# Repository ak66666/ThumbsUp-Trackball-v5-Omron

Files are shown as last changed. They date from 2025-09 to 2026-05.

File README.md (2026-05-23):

# ThumbsUp! Trackball v5 Omron
A version of v3 with Omron D2FC-7 switches used instead of Kailh Chocs.
PCB is used as button caps.

Finger-controlled configuration.
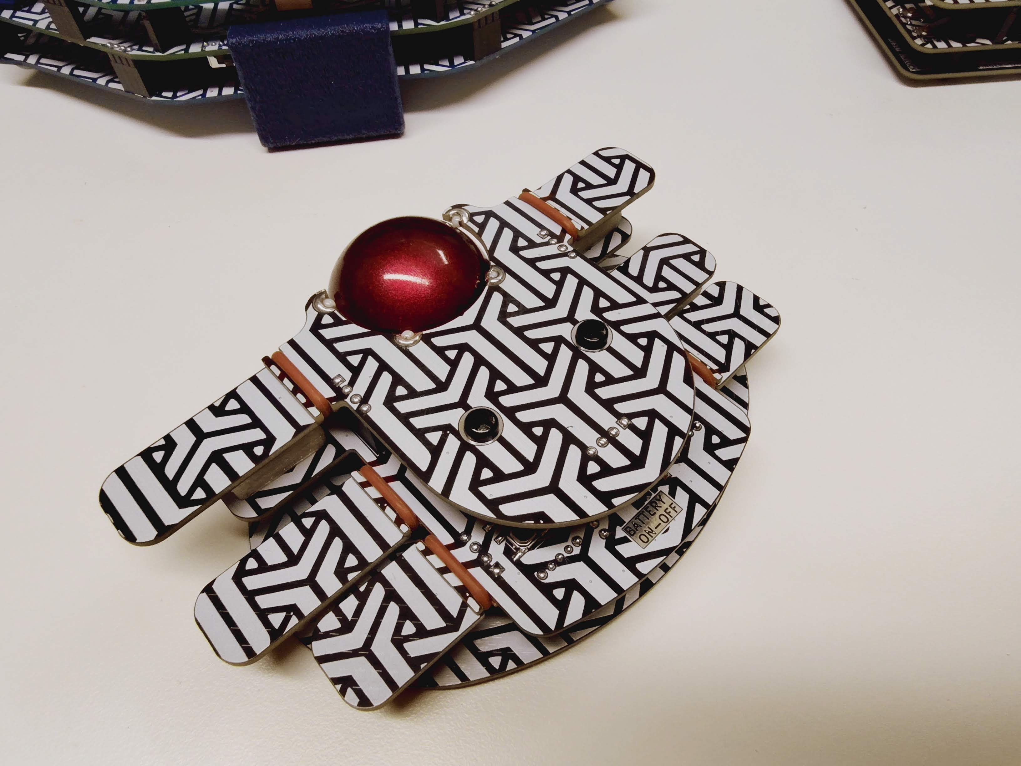
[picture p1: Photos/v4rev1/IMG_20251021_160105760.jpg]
Photos


For the thumb-operated mode a back(top) palm support is included.
For the right-hand operation mirror the model in slicer.

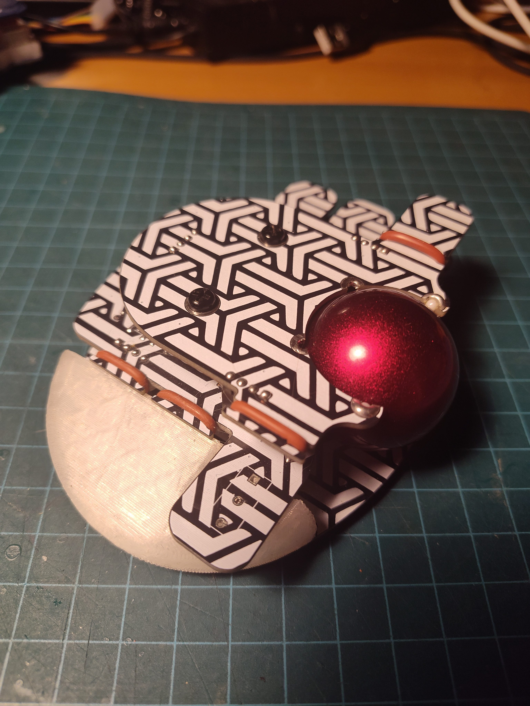
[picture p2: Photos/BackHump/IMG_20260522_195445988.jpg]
Photos

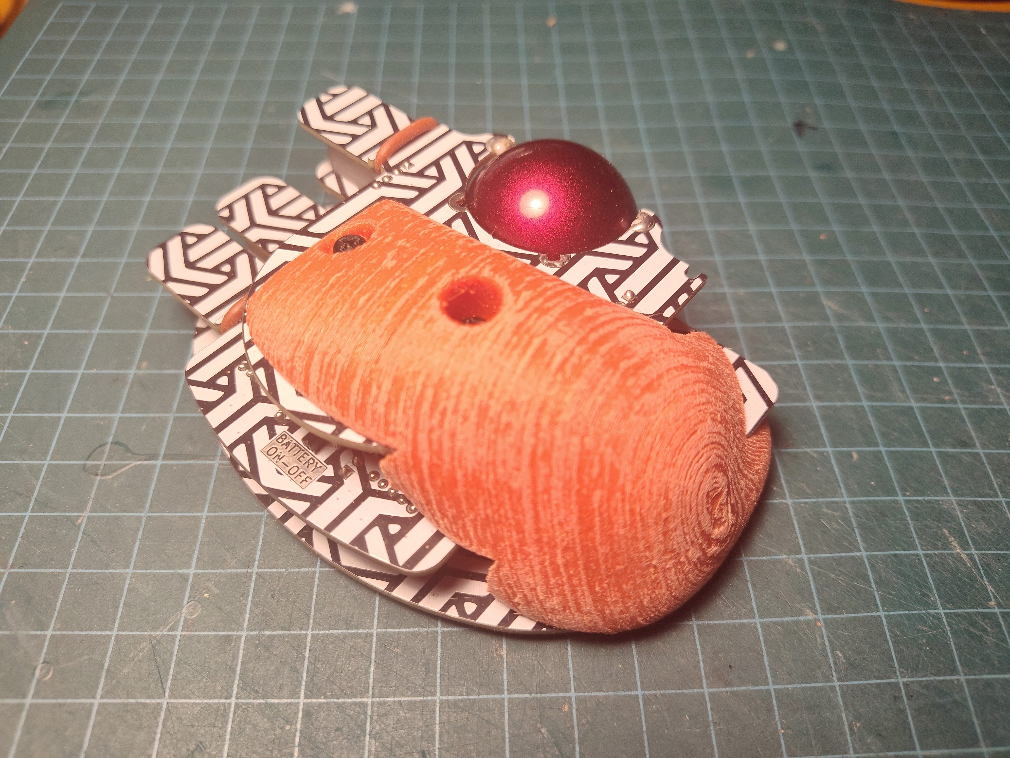
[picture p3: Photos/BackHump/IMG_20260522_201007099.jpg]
Photos

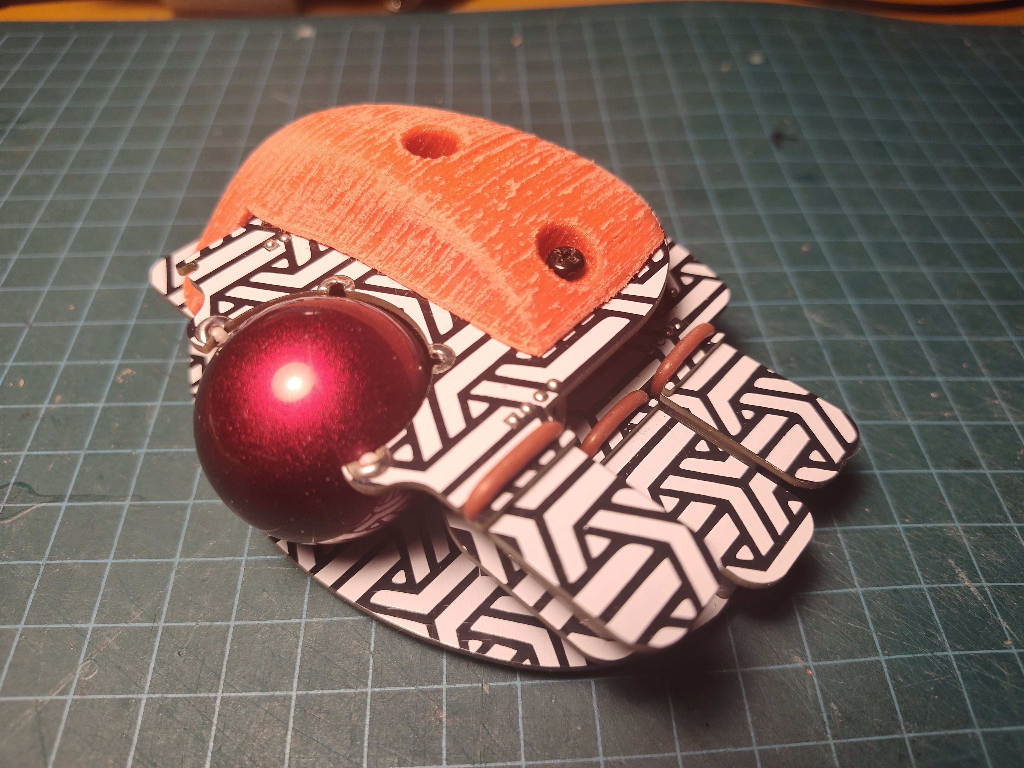
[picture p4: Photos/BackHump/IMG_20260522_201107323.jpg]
Photos

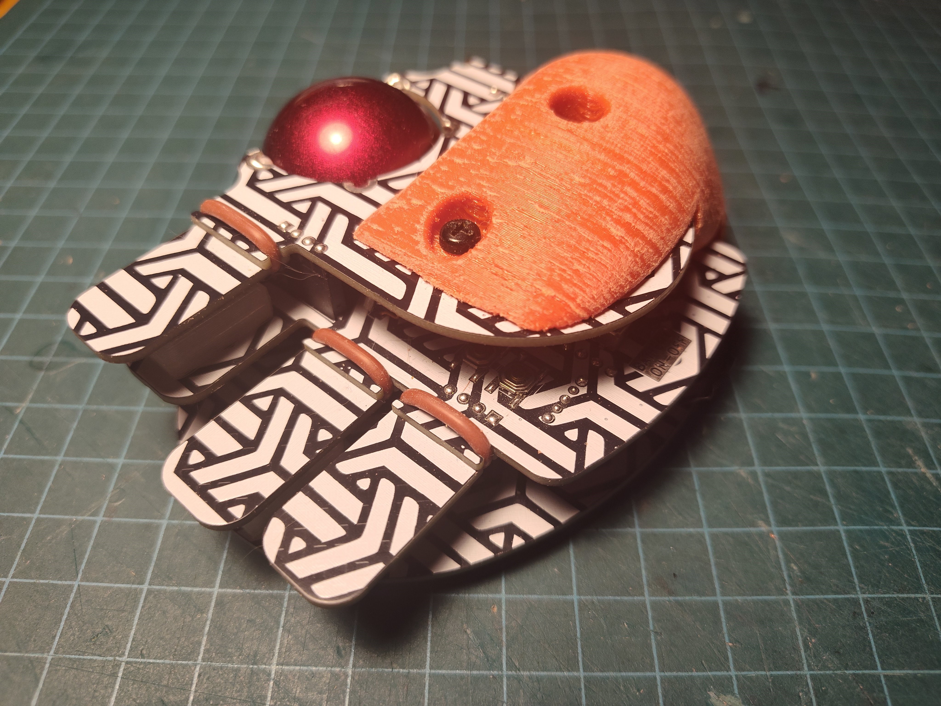
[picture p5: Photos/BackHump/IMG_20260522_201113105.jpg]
Photos


A PCB-based thumb-operated trackball, inspired by Elecom EX-G left hand trackball, Ploopy Nano trackball, and my own ThumbsUp! keyboards.

To be suitable for both left- and right-hand usage (in "portrairt" orientation), and also be finger-operated (in "landscape").
A three-position switch/soldering pad tells the device which mode to use - that will define the rotating direction.

It is a continuation of Trackball v3 - with the Kailh Choc switches replaced with Omron mouse buttons.
 
For MCU nice!nano v2 (and clones) with ZMK-based firmware is used (wired or wireless through Bluetooth or a dongle.)

34 mm ball, same as in Elecom EX-G.
For bearings - uxcell 2.5mm Ceramic Bearing Balls, ZrO2 Zirconium Oxide Ball, again, the same as used to improve my Elecom trackballs.
Bearings to be implanted into PCBs, no 3D-printed ball shroud/holder.

Other pictures in Photos folder.

# Firmware - same as v3

Original version with BT and wired connection:
https://github.com/ak66666/zmk-config-trackball.v3        

Dongle version:
https://github.com/ak66666/zmk-config-trackball.v3.dongle

Dongle version for a combo with ThumbsUp! v9 keyboard:
https://github.com/ak66666/zmk-config-trackball-v3-and-keyboard-v9.dongle

# For sale on Etsy
 
https://www.etsy.com/ca/listing/4390955764

# Assembly Instructions

Similar to v3:
https://thumbsupkeyboards.blogspot.com/2025/09/thumbsup-trackball-v3-assembly-steps.html

The difference is in the switches only.
3D printed switch bases are needed.
Below the switches there are three-point soldering connectors - you need to close two of them on the side where the switch button is.

# Gerber Generation

There is a little trick that needs to be applied to produce silkscreens with overlapping labels.
Normally all the elements on the silkscreen are added up, so the text would be interrupted/covered by the drawing elements.

To work around that limitation - use the generation option "Subtract Soldermask from Silkscreen".
IMPORTANT: Save and preserve the project files, you will be temporarily removing parts of the board design.

Labels which are covered by the silkscreen pattern, they should be moved to the front/back soldering mask layer.
Text needs to be inverted - check "Knockout" box in the label properties.
On the matching front/back silkscreen layer add a rectangle around the label. 
For the design time leave it unfilled - will fill it during Gerber file generation as described below.

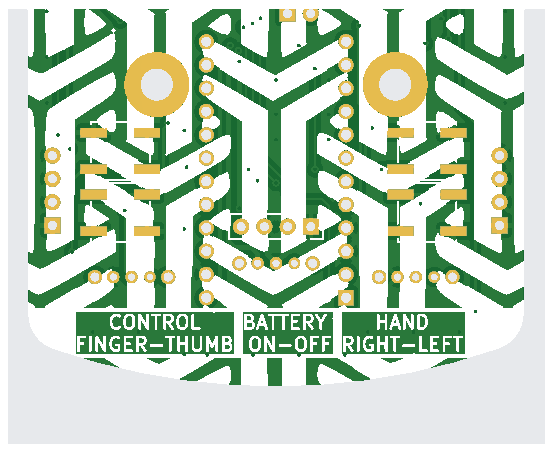
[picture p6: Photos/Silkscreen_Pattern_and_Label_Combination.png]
Photos


To generate fabrication files:
- In PCB Editor, for each of the PCB do the following (_do not_ save the file while doing that):
	- Select and delete all other PCBs, leave only one to be generated.
	- For each label on the solder mask layer - locate silkscreen rectangles around that label, modify its property - check "Filled Shape" box.
	  (Those boxes are not filled while designing the board, otherwise they cover all other elements.)
	- Generate the Gerbers (plotting, drilling files) with this:
		- Uncheck  "Subtract Soldermask from Silkscreen" option.
		- Exlude the silkscreens at this point.
	- Generate silkscreen layers with  "Subtract Soldermask from Silkscreen" option checked.
	- Close PCB Editor without saving the file.
	- Re-open PCB Editor and repeat these steps for other boards.
- Verify the genearted files.

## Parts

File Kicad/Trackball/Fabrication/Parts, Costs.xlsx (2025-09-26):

# | Part | Quantity | Price, CAD | Cost, CAD | Source
1 | PMW3610 sensor and lens | 1 | 5.99 | 5.99 | https://www.aliexpress.com/item/1005007118767775.html
2 | Nice!nano v2 (or clone) | 1 | 6.70 | 6.70 | https://www.aliexpress.com/item/1005006074191337.html
3 | 34mm ball | 1 | 19.08 | 19.08 | https://www.aliexpress.com/item/1005007857787050.html
4 | 3.7V 110mAh 301230 Lithium Polymer Li-Po Battery | 1 | 2.24 | 2.24 | https://www.aliexpress.com/item/1005003662352305.html
5 | Kailh Choc hot-swap sockets | 6 | 0.19 | 1.14 | https://www.aliexpress.com/item/1005003873653184.html
6 | Kailh Choc White Clicky swithces | 6 | 1.00 | 6.00
7 | Kailh Choc Key Cap | 6 | 1.00 | 6.00
8 | 12 Pin Headers Low profile, for Nice!nano. | 2 | 0.09 | 0.19 | https://www.aliexpress.com/item/1005007217493310.html
9 | 12 Pin Sockets, Low profile, for Nice!nano. | 2 | 0.42 | 0.85 | https://www.aliexpress.com/item/1005006248653180.html
10 | 4pin Sockets and pin headers for them for the board stands. | 7 | 0.02 | 0.16 | https://www.aliexpress.com/item/1005005258694395.html
11 | 4pin Sockets and pin headers for them for the board stands. | 7 | 0.11 | 0.77 | https://www.aliexpress.com/item/1005003610333849.html
12 | 2.5mm ZrO2 Ceramic Balls | 7 | 0.51 | 3.58 | https://www.aliexpress.com/item/1005008831542121.html
13 | Slide Switches (Power, Orientation, Handiness) | 3 | 0.49 | 1.48 | https://www.mouser.ca/ProductDetail/655-1825232-1
14 | 5x5mm Tactile Switches | 4 | 0.51 | 2.05 | https://www.mouser.ca/ProductDetail/611-PTS525SKG15JSMTR
15 | 6x 8x3mm Bumpons | 6 | 0.04 | 0.26 | https://www.aliexpress.com/item/1005005287385986.html
16 | Stand-offs w/nuts | 4 | 0.10 | 0.39 | https://www.amazon.ca/dp/B0BR5MT7R1
17 | 0.5 washers | 4 | 0.09 | 0.38 | https://www.amazon.ca/dp/B0F29B674L
18 | M3 screws | 4 | 0.10 | 0.42 | https://www.amazon.ca/dp/B07C72FBZ6
19 | PCB set | 1 | 60.00 | 60.00 | Price as sold at Etsy, less if ordered 20 sets from JLCPCB by yourself
 | Total without PCBs |  | 38.70
 | Total |  | 98.70

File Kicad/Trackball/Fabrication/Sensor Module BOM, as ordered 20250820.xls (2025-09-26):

Comment | Designator | Footprint | JLCPCB Part #
1m | C2 | C_0402_1005Metric | C14445
3.3uF/16V | C4 | C_0805_2012Metric | C15850
10k | R3 | R_0603_1608Metric | C25804
0.1u | C3,C1,C5,C6,C8 | C_0402_1005Metric | C1525
TCR2EF19 | U3 | SOT-23-5 | C27416
0.01u | C7,C9 | C_0402_1005Metric | C15195

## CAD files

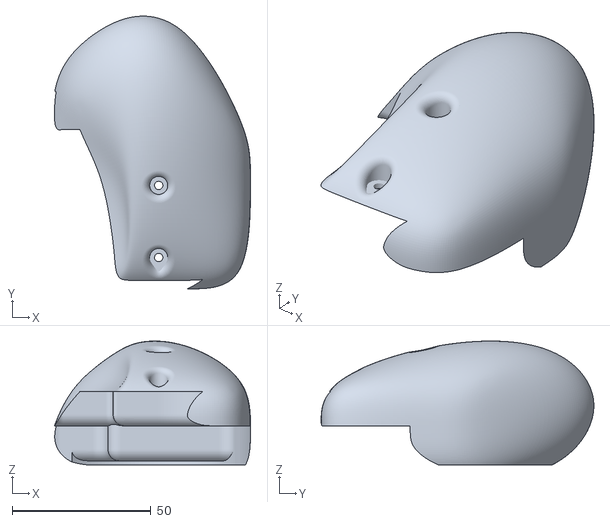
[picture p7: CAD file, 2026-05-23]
3D Parts/Hump2 Left.stl
70.6 x 98.2 x 44.6

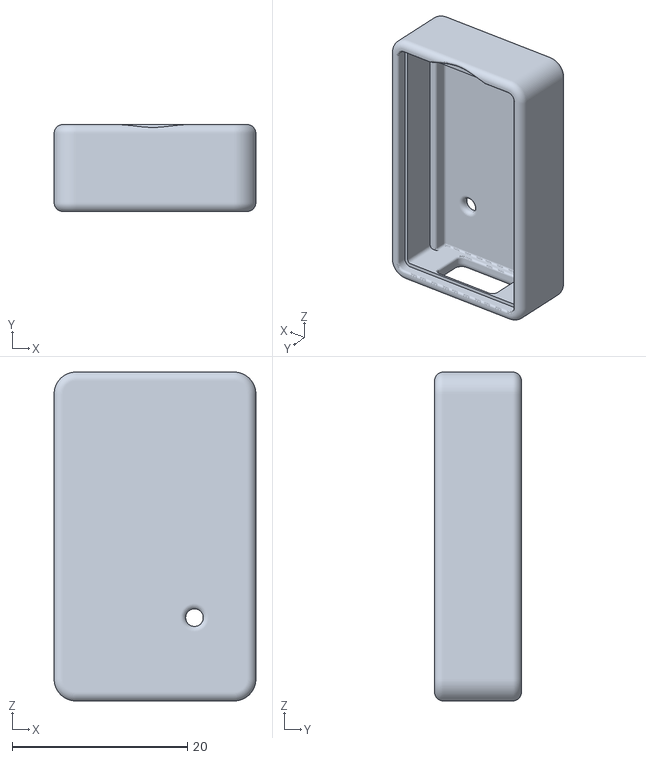
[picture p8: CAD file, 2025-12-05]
Dongle Case/Case.stl
23.0 x 9.90 x 37.5

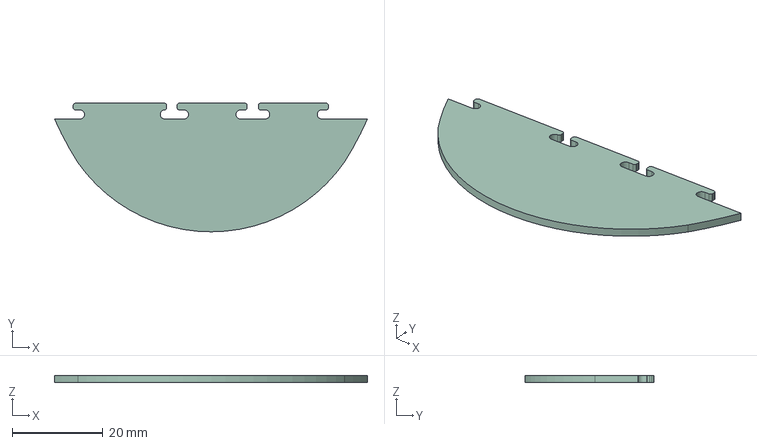
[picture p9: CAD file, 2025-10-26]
Kicad/Trackball/Palm Support/Palm Support.step
69.1 x 28.4 x 1.51 mm

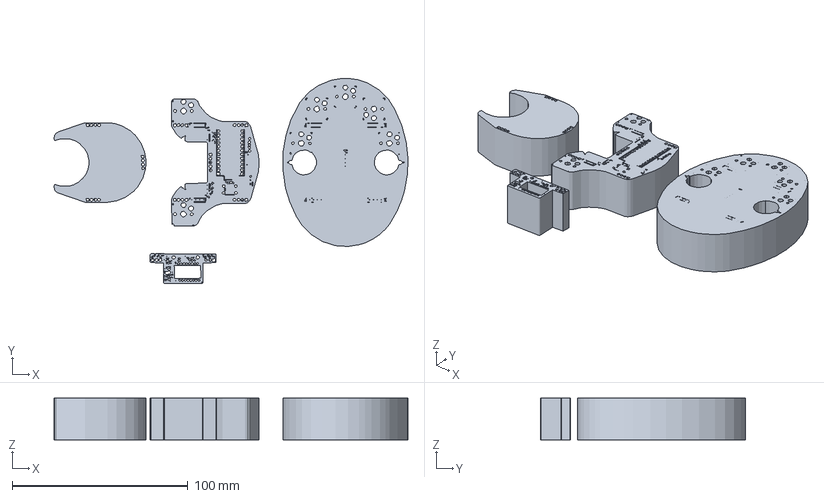
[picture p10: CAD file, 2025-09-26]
Kicad/Trackball/Pictures/PCBs.3mf
201.2 x 116.6 x 23.8 mm

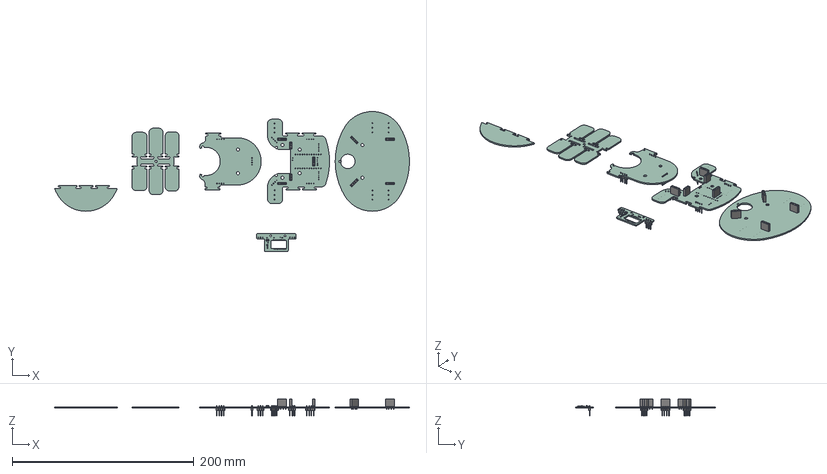
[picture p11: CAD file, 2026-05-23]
3D Parts/All Plates.step
391.0 x 154.1 x 18.7 mm
PinSocket_1x04_P2.54mm_Vertical x 7
C_0402_1005Metric x 8
PinSocket_1x03_P2.54mm_Vertical x 2
SOT-23-5
R_0603_1608Metric
C_0805_2012Metric
PinHeader_1x04_P2.54mm_Vertical x 7
PinHeader_1x03_P2.54mm_Vertical x 2
PinHeader_1x02_P2.54mm_Vertical
Trackball_PCB_1
Trackball_PCB_2
Trackball_PCB_3
Trackball_PCB_4
Trackball_PCB_5
Trackball_PCB_6

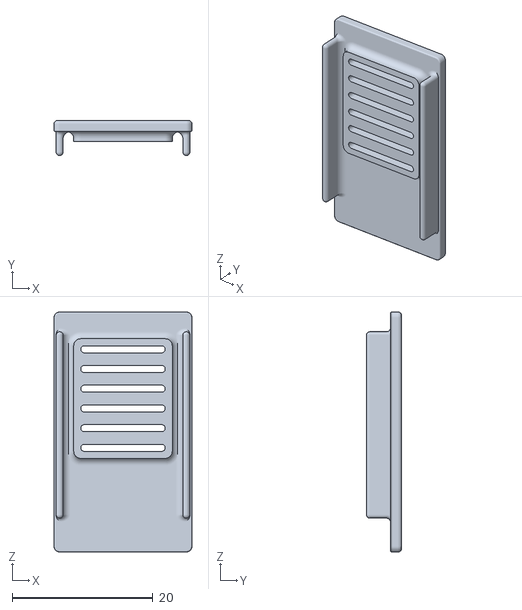
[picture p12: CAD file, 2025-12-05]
Dongle Case/Cover.stl
19.6 x 5.00 x 34.1

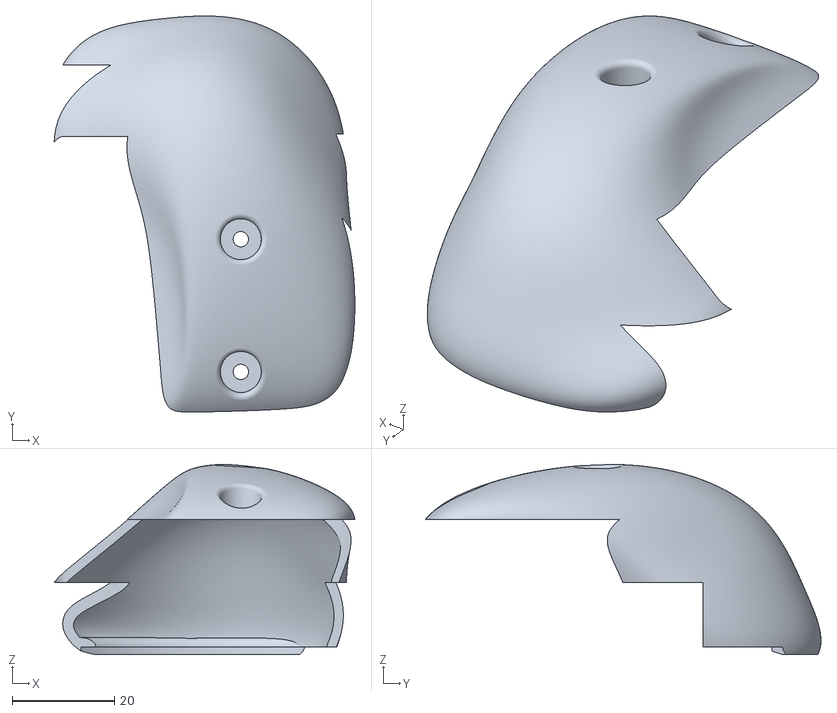
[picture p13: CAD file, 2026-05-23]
3D Parts/Hump Left.stl
58.8 x 77.5 x 37.2

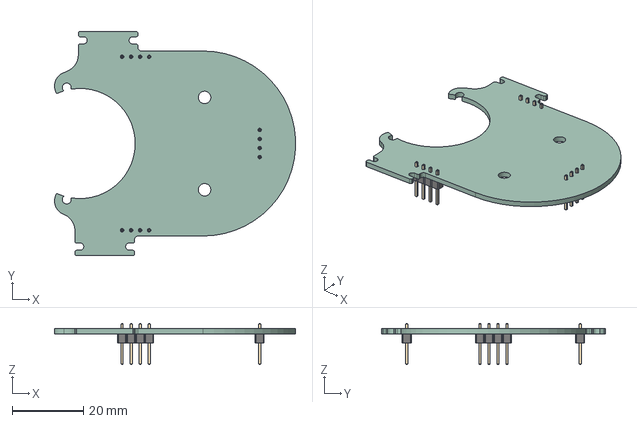
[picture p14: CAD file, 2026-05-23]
3D Parts/Top Plate.step
67.8 x 63.0 x 11.5 mm
PinHeader_1x04_P2.54mm_Vertical x 3
Trackball_PCB

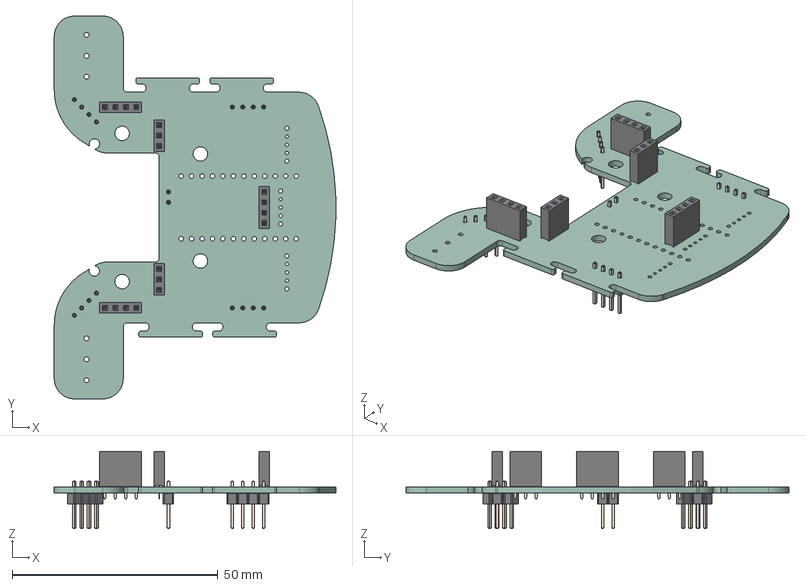
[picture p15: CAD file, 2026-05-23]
3D Parts/Middle Plate.step
68.4 x 93.0 x 18.7 mm
PinSocket_1x04_P2.54mm_Vertical x 3
PinSocket_1x03_P2.54mm_Vertical x 2
PinHeader_1x04_P2.54mm_Vertical x 4
PinHeader_1x02_P2.54mm_Vertical
Trackball_PCB

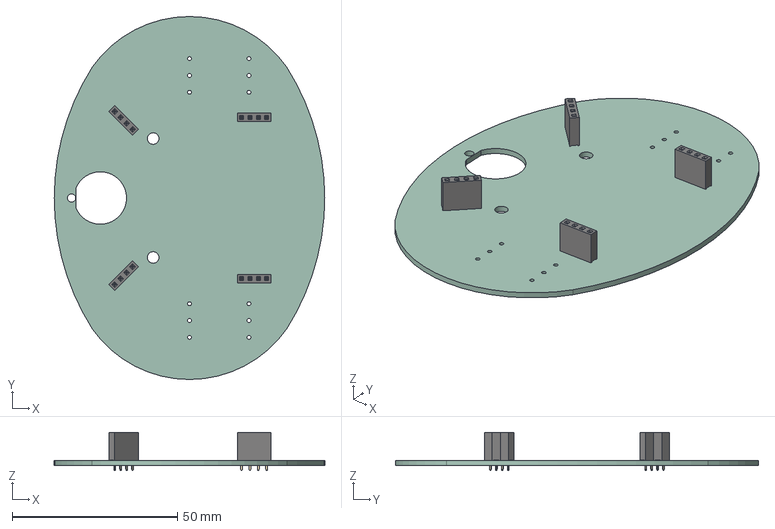
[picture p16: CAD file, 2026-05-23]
3D Parts/Bottom Plate.step
81.9 x 109.8 x 11.6 mm
PinSocket_1x04_P2.54mm_Vertical x 4
Trackball_PCB

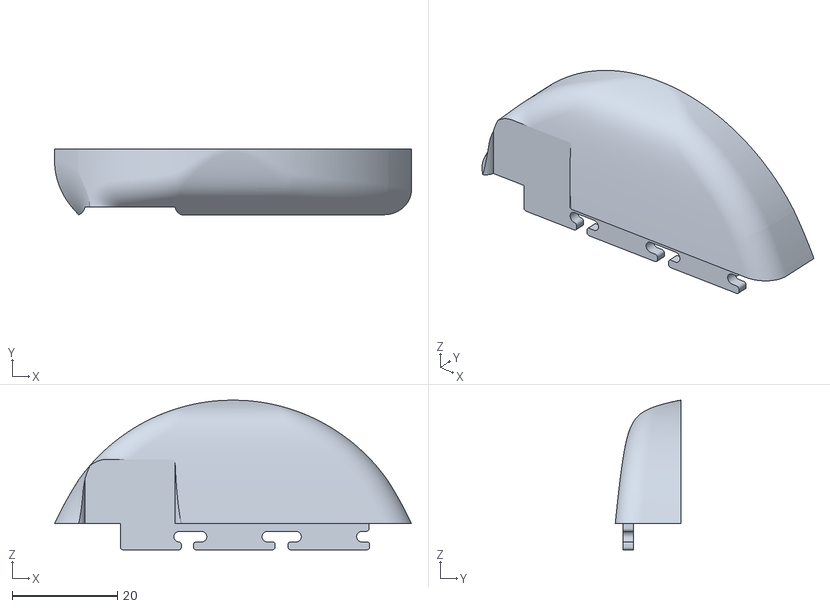
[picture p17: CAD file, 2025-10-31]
3D Parts/Palm Support.stl
67.8 x 12.4 x 28.4

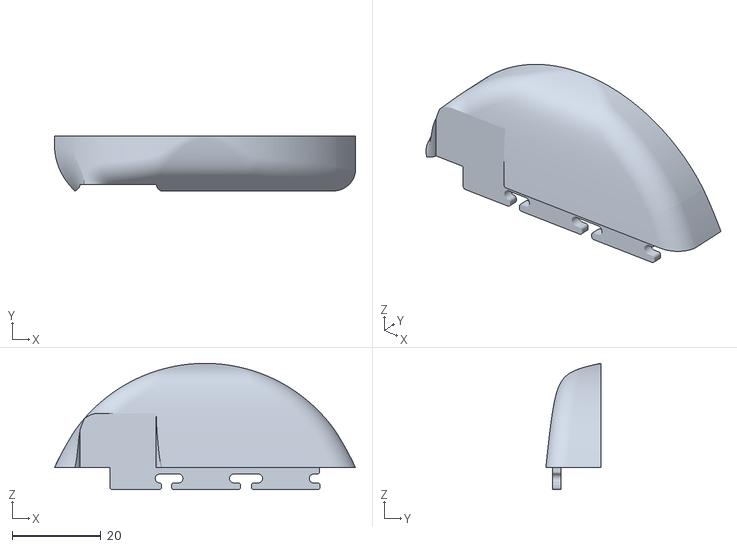
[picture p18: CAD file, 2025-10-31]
3D Parts/Palm Support Shell.stl
67.8 x 12.4 x 28.4

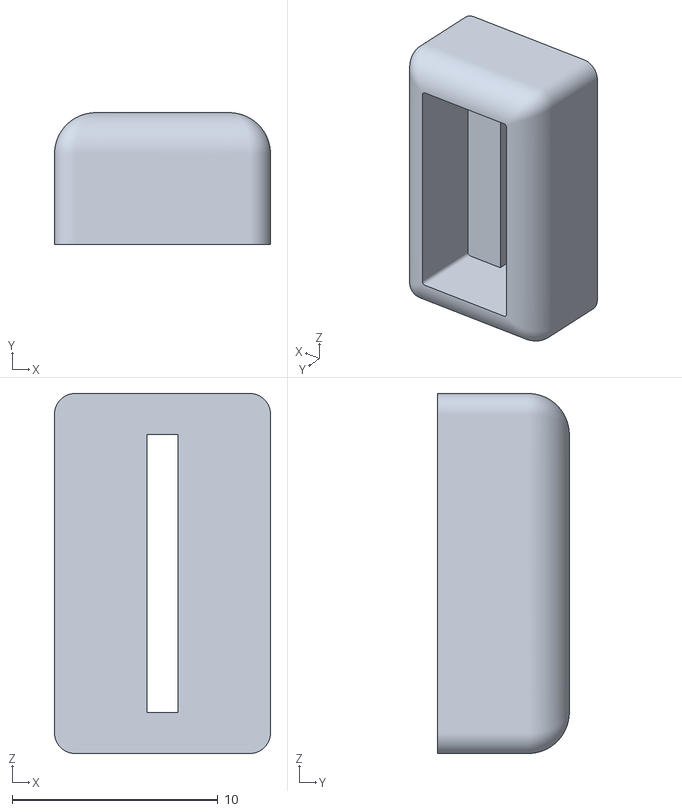
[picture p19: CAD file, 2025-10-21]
3D Parts/Switch Base 1.9.stl
10.5 x 6.40 x 17.5

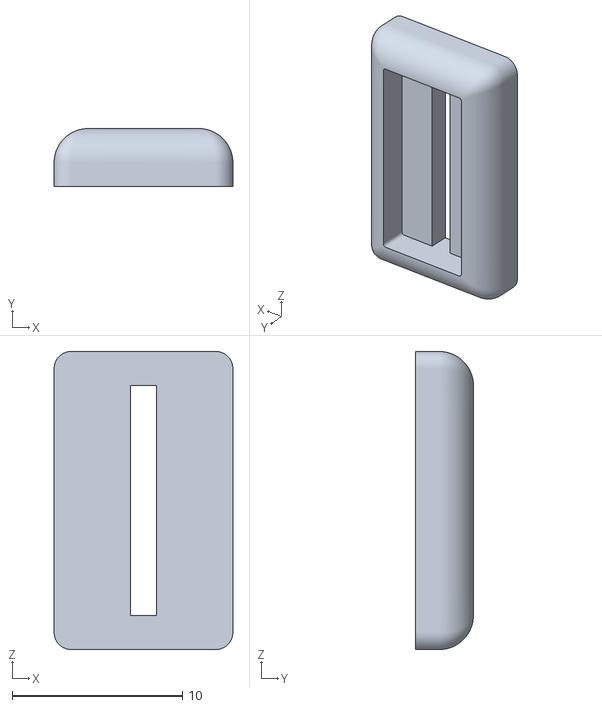
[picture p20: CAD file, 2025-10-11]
3D Parts/Switch Base Short.stl
10.5 x 3.40 x 17.5

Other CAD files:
3D Parts/Flap Holder.stl
3D Parts/Switch Base.stl
Kicad/Trackball/1825232-1/3D/1825232-1.stp
Kicad/Trackball/1825232-1/Allegro/18252321.psm
Kicad/Trackball/1825232-1/DEHDL/1825232_1/chips/chips.prt
Kicad/Trackball/Palm Support/Palm Support.stl

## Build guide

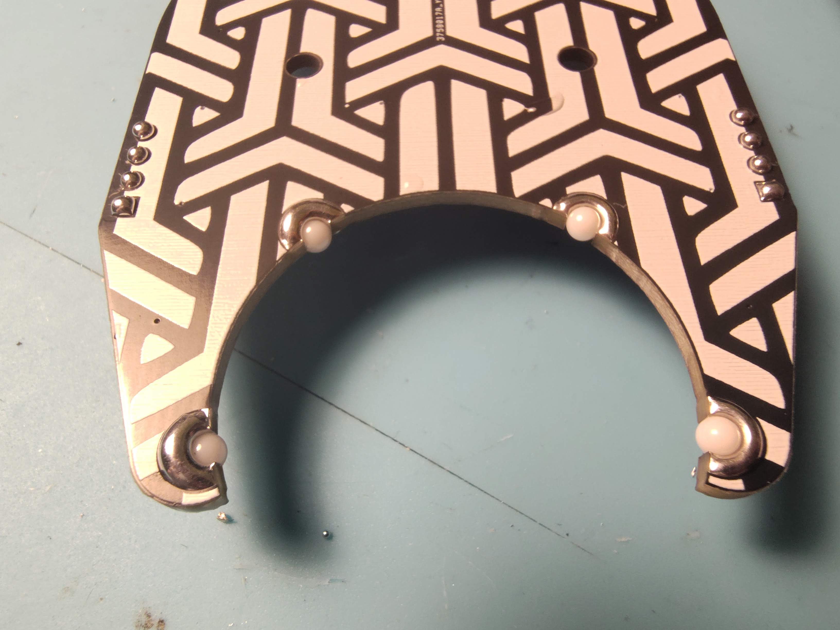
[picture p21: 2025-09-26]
Photos/Assembly Process/IMG_20250912_122234433.jpg

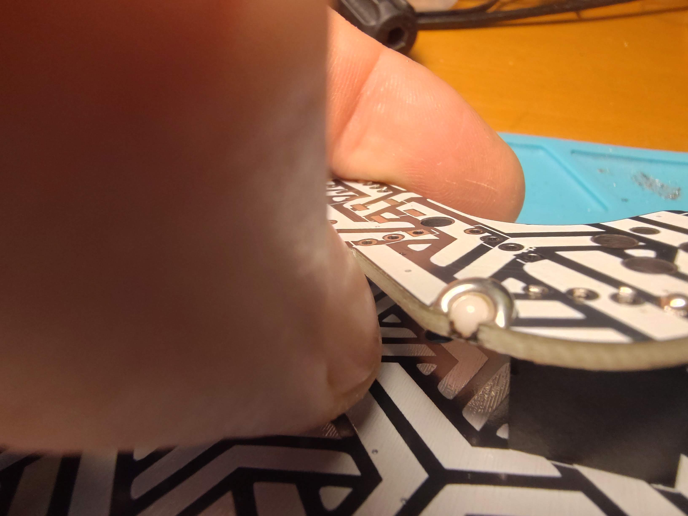
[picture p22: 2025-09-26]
Photos/Assembly Process/IMG_20250912_110531941_HDR.jpg

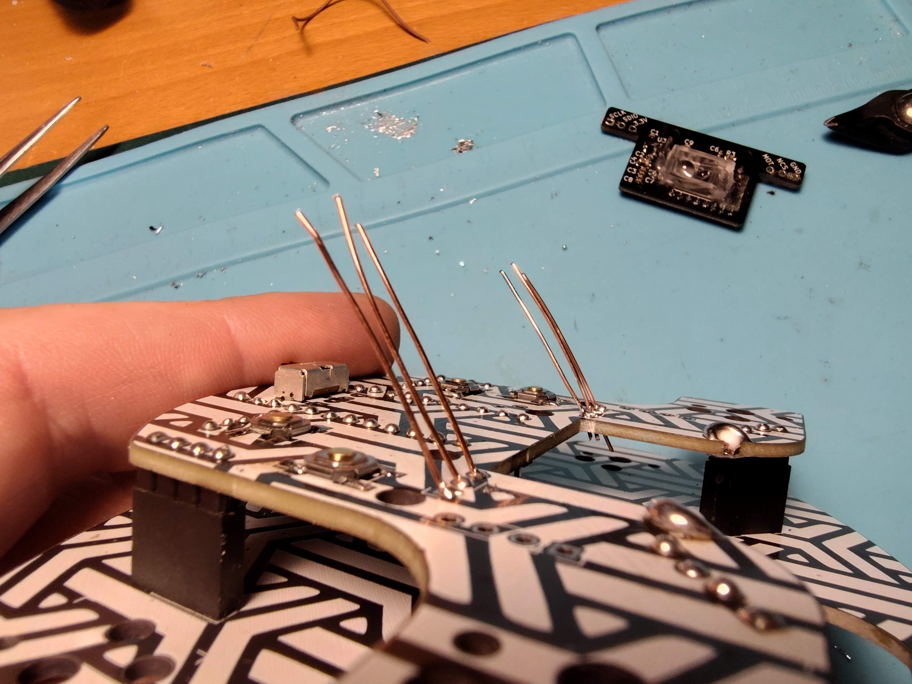
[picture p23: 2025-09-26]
Photos/Assembly Process/IMG_20250912_113103635_HDR.jpg

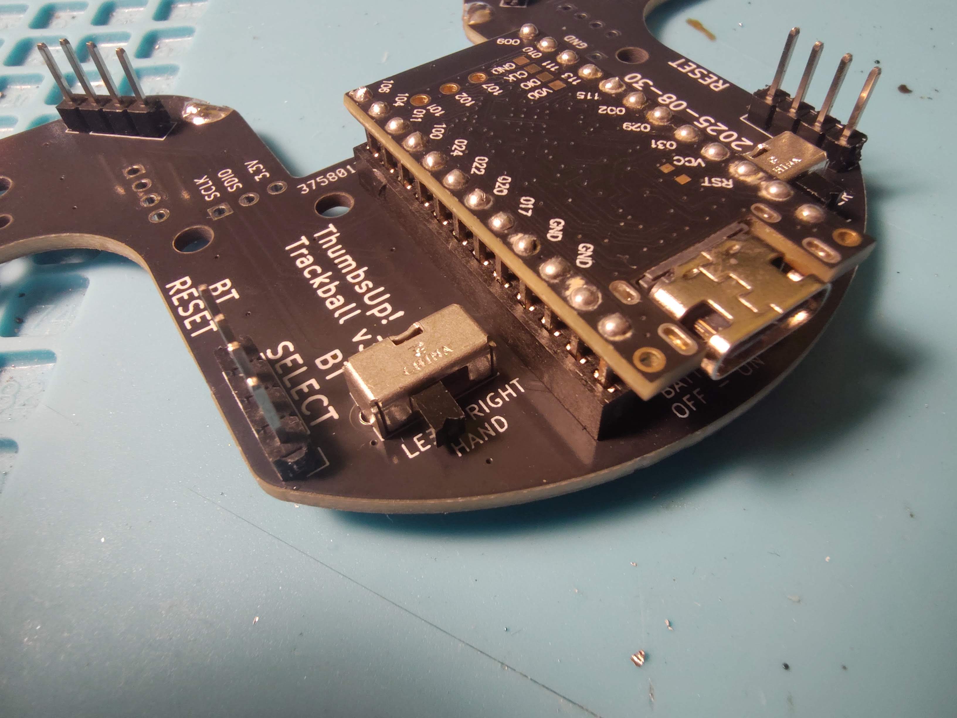
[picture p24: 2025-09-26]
Photos/Assembly Process/IMG_20250912_111534861.jpg

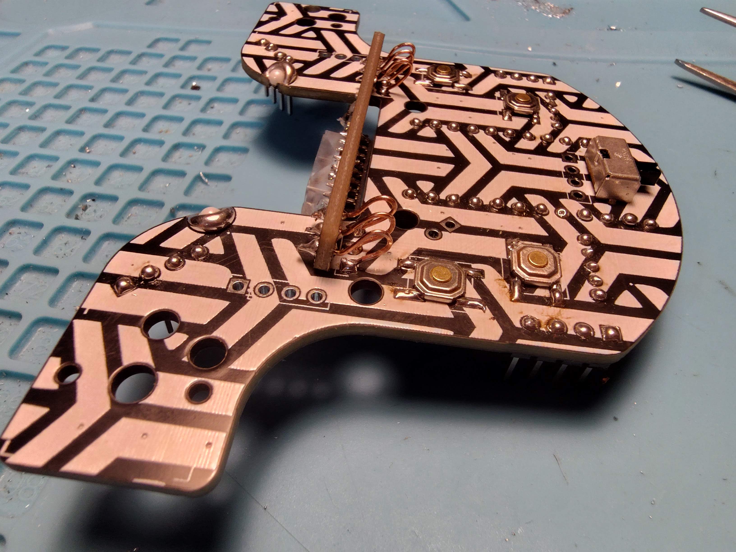
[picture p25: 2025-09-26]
Photos/Assembly Process/IMG_20250912_114000764_HDR.jpg

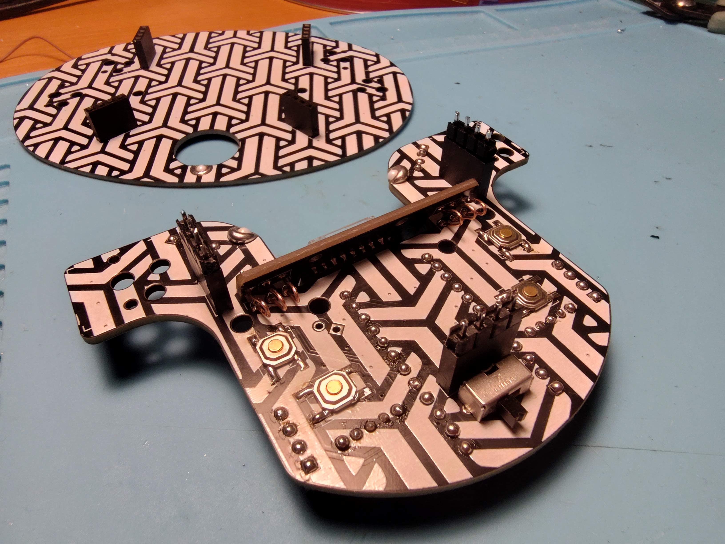
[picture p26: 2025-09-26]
Photos/Assembly Process/IMG_20250912_120129462_HDR.jpg

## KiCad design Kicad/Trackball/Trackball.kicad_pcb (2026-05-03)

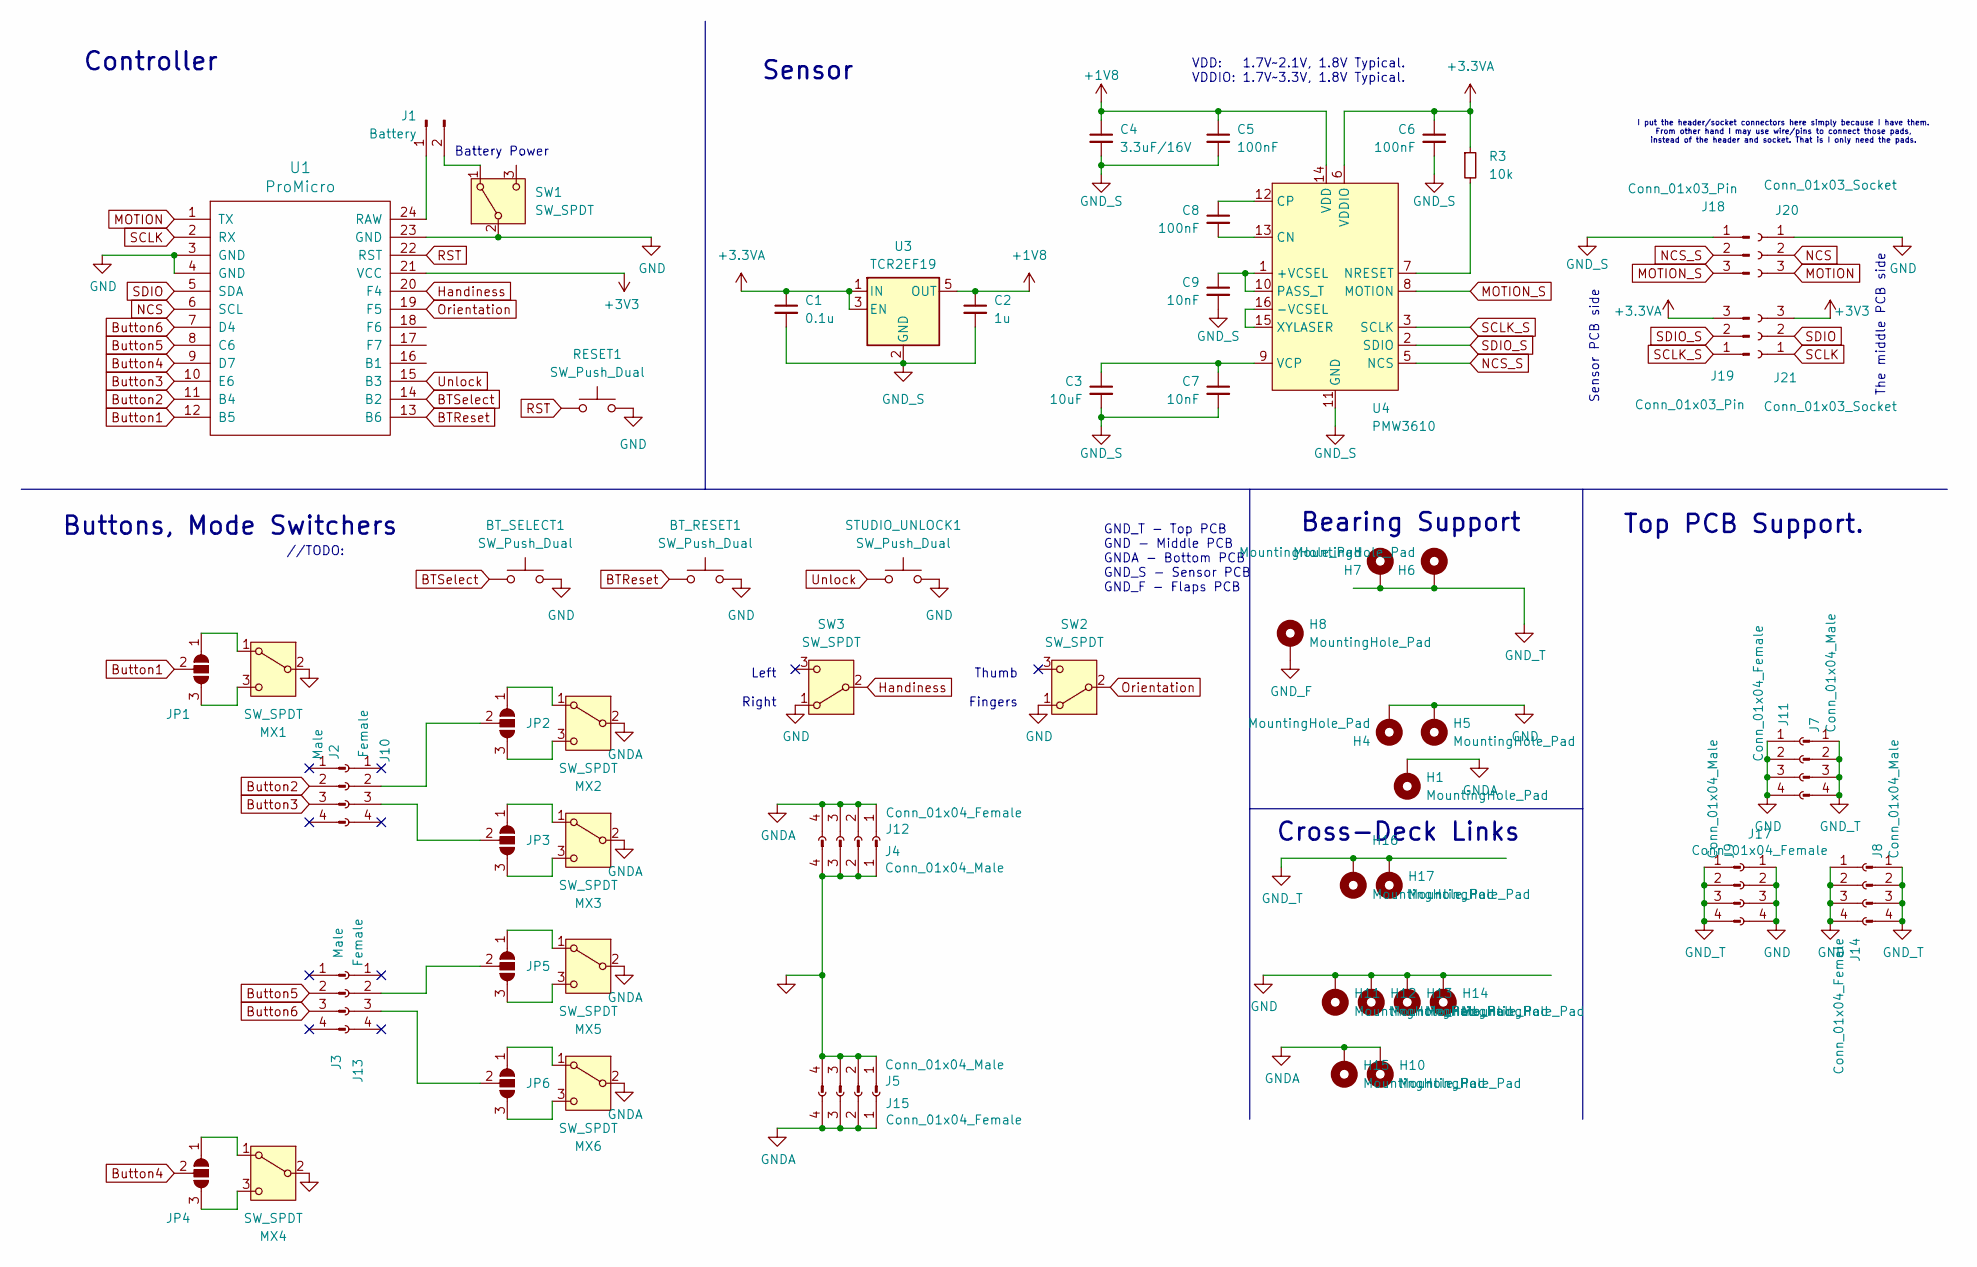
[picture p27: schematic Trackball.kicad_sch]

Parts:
BT_RESET1: SW_Push_Dual; SW_Push_1P1T_NO_CK_KSC6xxJ
BT_SELECT1: SW_Push_Dual; SW_Push_1P1T_NO_CK_KSC6xxJ
C1: 0.1u; C_0402_1005Metric
C2: 1u; C_0402_1005Metric
C3: 10uF; C_0402_1005Metric; MFR. Part # CL21A106KAYNNNE; JLCPCB Part # C15850
C4: 3.3uF/16V; C_0805_2012Metric; MFR. Part # TCC0805X7R335K250FT; JLCPCB Part # C7393948
C5, C6, C8: 100nF; C_0402_1005Metric; MFR. Part # CC0603KRX7R9BB104; JLCPCB Part # C14663
C7, C9: 10nF; C_0402_1005Metric; MFR. Part # 0603B103K500NT; JLCPCB Part # C57112
H1, H4, H5, H6, H7, H8: MountingHole_Pad; MountingHole_2.5mm_Pad
H10, H11, H12, H13, H14, H15, H16, H17: MountingHole_Pad; MountingHole_3.5mm_Pad
J1: Battery; PinHeader_1x02_P2.54mm_Vertical
J2, J3: Male; PinHeader_1x04_P2.54mm_Vertical
J4, J5, J7, J8, J9: Conn_01x04_Male; PinHeader_1x04_P2.54mm_Vertical
J10, J13: Female; PinSocket_1x04_P2.54mm_Vertical
J11, J12, J14, J15, J17: Conn_01x04_Female; PinSocket_1x04_P2.54mm_Vertical
J18, J19: Conn_01x03_Pin; PinHeader_1x03_P2.54mm_Vertical
J20, J21: Conn_01x03_Socket; PinSocket_1x03_P2.54mm_Vertical
JP1, JP2, JP3, JP4, JP5, JP6: SolderJumper_3_Open; SolderJumper-3_P1.3mm_Open_RoundedPad1.0x1.5mm
MX1, MX2, MX3, MX4, MX5, MX6: SW_SPDT; SW_D2FC_OMR
R3: 10k; R_0603_1608Metric; MFR. Part # 0603WAF1002T5E; JLCPCB Part # C25804
RESET1: SW_Push_Dual; SW_Push_1P1T_NO_CK_KSC6xxJ
STUDIO_UNLOCK1: SW_Push_Dual; SW_Push_1P1T_NO_CK_KSC6xxJ
SW1, SW2, SW3: SW_SPDT; 18252321
U1: ProMicro
U3: TCR2EF19; SOT-23-5
U4: PMW3610; PMW3610DM-SUDU 16Pin; MFR. Part # PMW3610DM-SUDU; JLCPCB Part # C42442560

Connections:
+1V8: C2.1, C4.1, C5.1, U3.5 (OUT), U4.14 (VDD)
+3.3VA: C1.1, C6.1, J19.3, R3.1, U3.1 (IN), U3.3 (EN), U4.6 (VDDIO)
+3V3: J21.3, U1.21 (VCC)
BTReset: BT_RESET1.1, U1.13 (B6)
BTSelect: BT_SELECT1.1, U1.14 (B2)
Button1: JP1.2 (C), U1.12 (B5)
Button2: J2.2, U1.11 (B4)
Button3: J2.3, U1.10 (E6)
Button4: JP4.2 (C), U1.9 (D7)
Button5: J3.2, U1.8 (C6)
Button6: J3.3, U1.7 (D4)
GND: BT_RESET1.2, BT_SELECT1.2, H4.1, H5.1, H11.1, H12.1, H13.1, H14.1, J4.1, J4.2, J4.3, J4.4, J5.1, J5.2, J5.3, J5.4, J11.1, J11.2, J11.3, J11.4, J14.1, J14.2, J14.3, J14.4, J17.1, J17.2, J17.3, J17.4, J20.1, MX1.2 (B), MX4.2 (B), RESET1.2, STUDIO_UNLOCK1.2, SW1.2 (B), SW2.1 (A), SW3.1 (A), U1.3 (GND), U1.4 (GND), U1.23 (GND)
GNDA: H1.1, H10.1, H15.1, J12.1, J12.2, J12.3, J12.4, J15.1, J15.2, J15.3, J15.4, MX2.2 (B), MX3.2 (B), MX5.2 (B), MX6.2 (B)
GND_F: H8.1
GND_S: C1.2, C2.2, C3.2, C4.2, C5.2, C6.2, C7.2, C9.2, J18.1, U3.2 (GND), U4.11 (GND)
GND_T: H6.1, H7.1, H16.1, H17.1, J7.1, J7.2, J7.3, J7.4, J8.1, J8.2, J8.3, J8.4, J9.1, J9.2, J9.3, J9.4
Handiness: SW3.2 (B), U1.20 (F4)
MOTION: J20.3, U1.1 (TX)
MOTION_S: J18.3, U4.8 (MOTION)
NCS: J20.2, U1.6 (SCL)
NCS_S: J18.2, U4.5 (NCS)
unnamed: J1.1, U1.24 (RAW)
unnamed: J1.2, SW1.1 (A)
unnamed: J10.2, JP2.2 (C)
unnamed: J10.3, JP3.2 (C)
unnamed: J13.2, JP5.2 (C)
unnamed: J13.3, JP6.2 (C)
unnamed: JP1.1 (A), MX1.1 (A)
unnamed: JP1.3 (B), MX1.3 (C)
unnamed: JP2.1 (A), MX2.1 (A)
unnamed: JP2.3 (B), MX2.3 (C)
unnamed: JP3.1 (A), MX3.1 (A)
unnamed: JP3.3 (B), MX3.3 (C)
unnamed: JP4.1 (A), MX4.1 (A)
unnamed: JP4.3 (B), MX4.3 (C)
unnamed: JP5.1 (A), MX5.1 (A)
unnamed: JP5.3 (B), MX5.3 (C)
unnamed: JP6.1 (A), MX6.1 (A)
unnamed: JP6.3 (B), MX6.3 (C)
unnamed: C9.1, U4.1 (+VCSEL), U4.10 (PASS_T)
unnamed: U4.15 (XYLASER), U4.16 (-VCSEL)
unnamed: C8.2, U4.13 (CN)
unnamed: C8.1, U4.12 (CP)
unnamed: R3.2, U4.7 (NRESET)
unnamed: C3.1, C7.1, U4.9 (VCP)
Orientation: SW2.2 (B), U1.19 (F5)
RST: RESET1.1, U1.22 (RST)
SCLK: J21.1, U1.2 (RX)
SCLK_S: J19.1, U4.3 (SCLK)
SDIO: J21.2, U1.5 (SDA)
SDIO_S: J19.2, U4.2 (SDIO)
Unlock: STUDIO_UNLOCK1.1, U1.15 (B3)

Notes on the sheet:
//TODO:
VDD: 1.7V~2.1V, 1.8V Typical. VDDIO: 1.7V~3.3V, 1.8V Typical.
Battery Power
I put the header/socket connectors here simply because I have them. From other hand I may use wire/pins to connect those pads, instead of the header and socket. That is I only need the pads.
GND_T - Top PCB GND - Middle PCB GNDA - Bottom PCB GND_S - Sensor PCB GND_F - Flaps PCB
Top PCB Support.
The middle PCB side
Sensor PCB side
Thumb Fingers
Buttons, Mode Switchers
Controller
Bearing Support
Cross-Deck Links
Sensor
Left Right

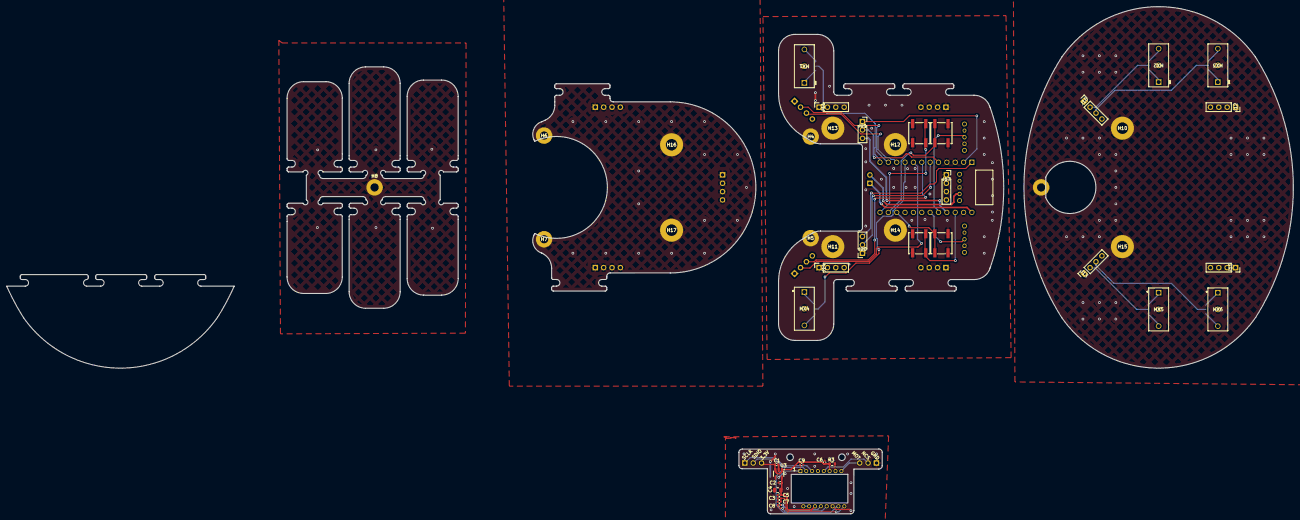
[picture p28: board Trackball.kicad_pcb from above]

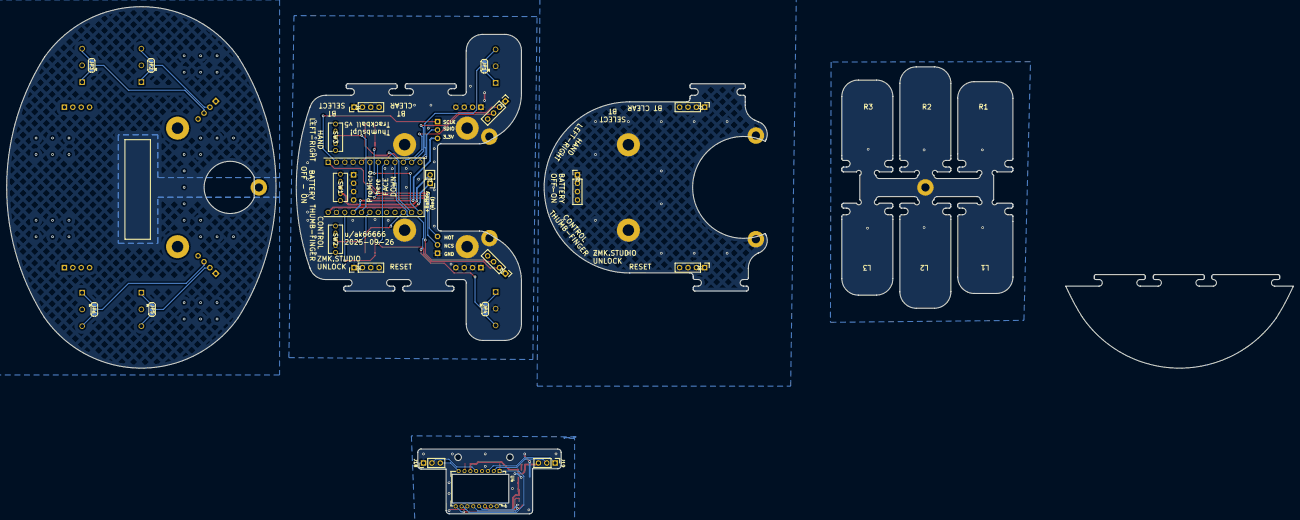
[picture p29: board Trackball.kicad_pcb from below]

Board: 2 copper layers, 391.0 x 154.1 mm, 65 parts (20 on the bottom side), 51 nets.

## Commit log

2025-09-26 B5: First draft version.
    [1825232-1.SchLib, 1825232-1.stp, 18252321.PcbLib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]
2025-09-26 B5: Replaced switches, added soldering pad switches to configure the button switch orientation, added break-outs to detach the flaps over the switches.
    [Trackball.kicad_pcb, Trackball.kicad_sch]
2025-09-26 B5: Tried to upload to JLC, corrected the labels, error-checked.
    [Trackball-B_Adhesive.gbr, Trackball-B_Cu.gbr, Trackball-B_Fab.gbr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]
2025-09-26 B5: As ordered 20250926.
    [Trackball-B_Cu.gbr, Trackball-B_Mask.gbr, Trackball-B_Paste.gbr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]
2025-10-11 B5: Separated key flaps into a separate panel. Added photos of rev.1 device.
    [Flap Holder.stl, Switch Base Short.stl, Switch Base.stl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]
2025-10-11 B5: Fixed the validation errors, ready to regenerate Gerbers
    [Trackball.kicad_pcb]
2025-10-11 B5: Created Gerbers, loaded them to JLCPCB, not ordered yet.
    [Trackball-B_Cu.gbr, Trackball-B_Mask.gbr, Trackball-B_Paste.gbr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]
2025-10-21 B5: Added photos, updated readme.
    [Switch Base 1.9.stl]
2025-10-24 B5: Modified the flaps plate - changed their length as per user feedback. Updated Gerbers for that plate, ordered that plate 20251024.
    [Trackball-B_Cu.gbr, Trackball-B_Mask.gbr, Trackball-B_Paste.gbr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]
2025-10-26 B5: Added a 3D-printed palm support piece.
    [Palm Support.step, Palm Support.stl, Trackball.kicad_pcb]
2025-10-31 B5: Corrected the 3D-printed palm support piece, now it properly fits in its place.
    [Palm Support Shell.stl, Palm Support.stl]
2025-12-05 B3: Replaced the dongle files.
    [Case.stl, Cover.stl, Dongle Case.stl]
2026-02-05 B5: Uploaded STEP files for the plates
    [Bottom Plate.step, Middle Plate.step, Top Plate.step]
2026-05-03 B5: Rev.1 changes.
    [Trackball.kicad_pcb, Trackball.kicad_sch]
2026-05-03 B5: Refreshed Gerbers, as ordered 2026-05-03.
    [Trackball-B_Adhesive.gbr, Trackball-B_Courtyard.gbr, Trackball-B_Cu.gbr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]
2026-05-23 B5: Photos added.
    [All Plates.step, Bottom Plate.step, Hump Left.stl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]
